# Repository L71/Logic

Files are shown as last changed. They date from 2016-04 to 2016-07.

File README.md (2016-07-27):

Logic signal processing Eurorack modules
========================================

* 4520 - 8bit binary counter/clock divider. Can trigger on both clock signal edges (determined by which input is used). 

* 234 - Sync clock divider, one pulse out for every 2,3 or 4 in. 

* Trigger - small module with 2x gate rising edge detectors, 2x inverters with button. Additional ORed output for the two edge detector outputs.

Panels and PCBs licensed cc-by-sa.

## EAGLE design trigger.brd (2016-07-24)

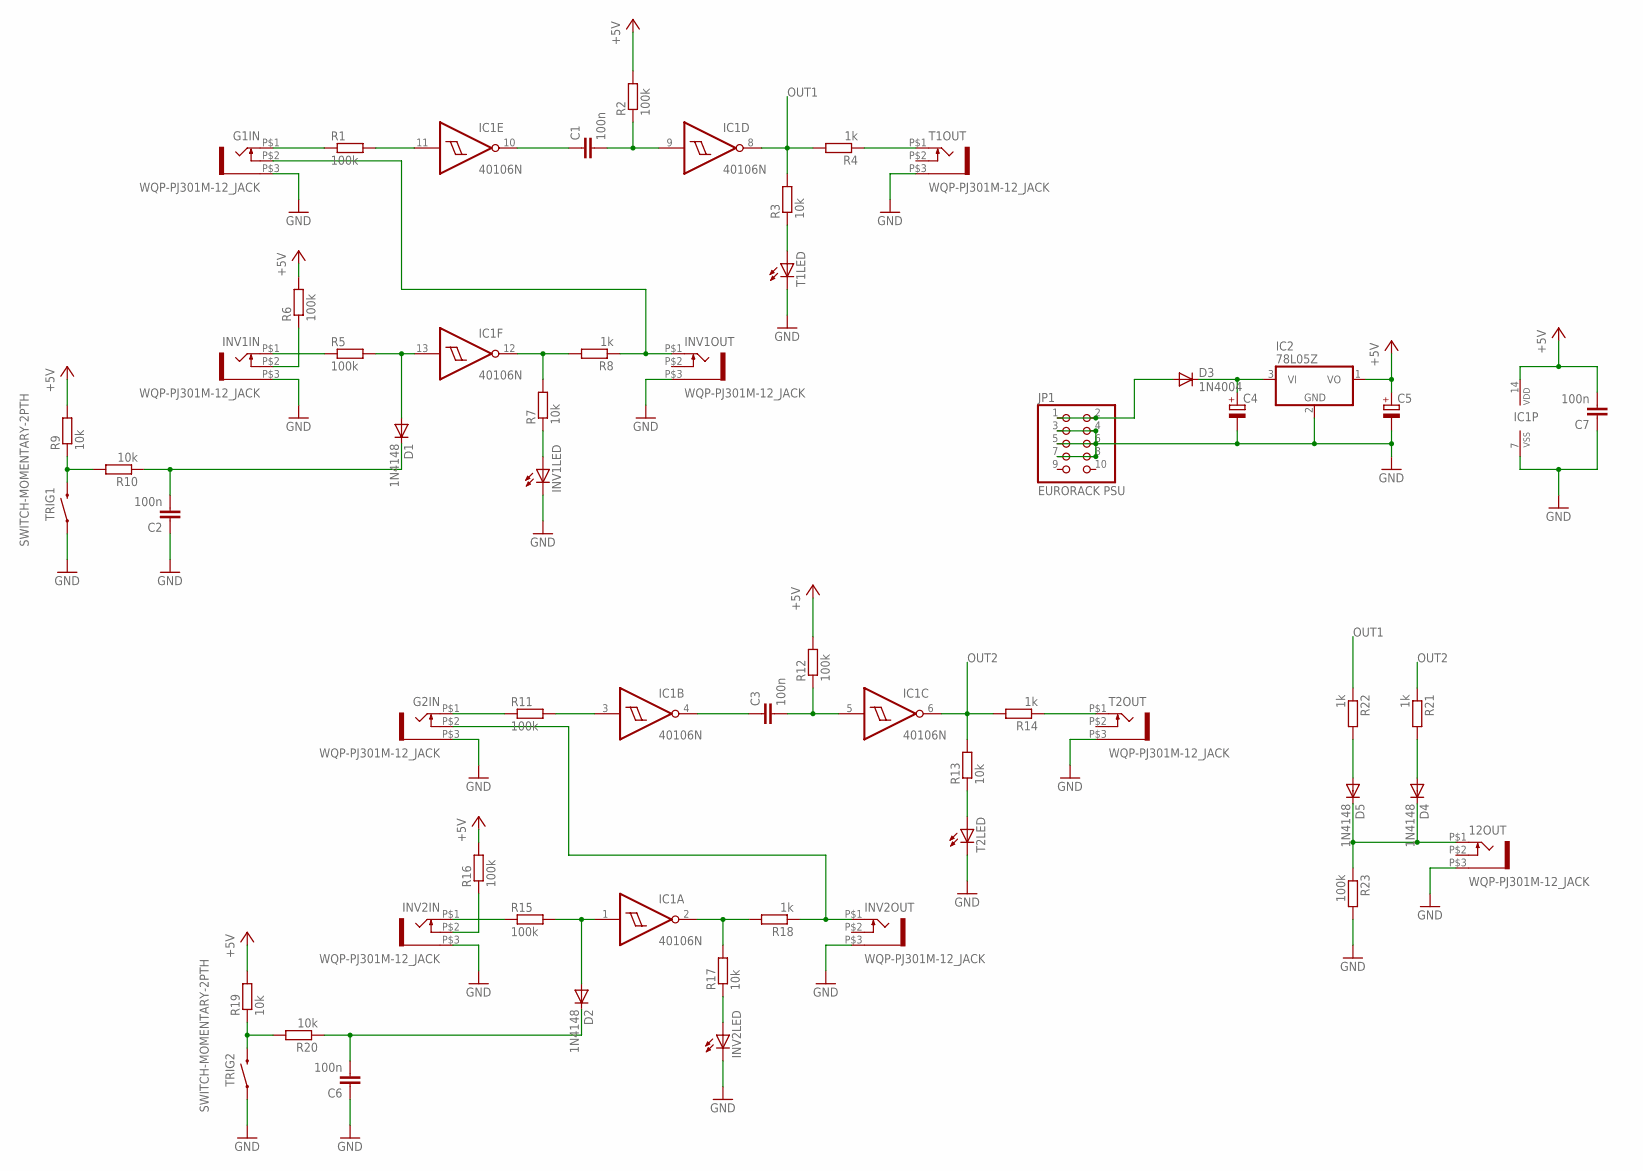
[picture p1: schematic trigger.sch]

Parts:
12OUT: WQP-PJ301M-12_JACK
C1, C2, C3, C6, C7: 100n; C025-025X050
C4, C5: CPOL-EUE2.5-5; E2,5-5
D1, D2, D4, D5: 1N4148; D-2.5
D3: 1N4004; D-2.5
G1IN, G2IN: WQP-PJ301M-12_JACK
IC1: 40106N; DIL14
IC2: 78L05Z; TO92
INV1IN, INV1OUT, INV2IN, INV2OUT: WQP-PJ301M-12_JACK
INV1LED, INV2LED: LED3MM
JP1: EURORACK PSU; 2X05
R1, R2, R5, R6, R11, R12, R15, R16, R23: 100k; 0204V
R3, R7, R9, R10, R13, R17, R19, R20: 10k; 0204V
R4, R8, R14, R18, R21, R22: 1k; 0204V
T1LED, T2LED: LED3MM
T1OUT, T2OUT: WQP-PJ301M-12_JACK
TRIG1, TRIG2: SWITCH-MOMENTARY-2PTH; TACTILE-PTH

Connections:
+5V: C5.+, C7.2, IC1.14 (VDD), IC2.1 (VO), R2.2, R6.2, R9.2, R12.2, R16.2, R19.2
+12V_IN: D3.A, JP1.1, JP1.2
GND: 12OUT.P$3 (1), C2.1, C4.-, C5.-, C6.1, C7.1, G1IN.P$3 (1), G2IN.P$3 (1), IC1.7 (VSS), IC2.2 (GND), INV1IN.P$3 (1), INV1LED.K (C), INV1OUT.P$3 (1), INV2IN.P$3 (1), INV2LED.K (C), INV2OUT.P$3 (1), JP1.3, JP1.4, JP1.5, JP1.6, JP1.7, JP1.8, R23.2, T1LED.K (C), T1OUT.P$3 (1), T2LED.K (C), T2OUT.P$3 (1), TRIG1.1, TRIG2.1
IN_1: G1IN.P$1 (2), R1.1
unnamed: 12OUT.P$1 (2), D4.C, D5.C, R23.1
unnamed: IC1.11 (I), R1.2
unnamed: C1.1, IC1.10 (O)
unnamed: C1.2, IC1.9 (I), R2.1
unnamed: D5.A, R22.2
unnamed: R3.1, T1LED.A
unnamed: R4.1, T1OUT.P$1 (2)
unnamed: IC1.12 (O), R7.2, R8.2
unnamed: INV1LED.A, R7.1
unnamed: G1IN.P$2 (3), INV1OUT.P$1 (2), R8.1
unnamed: INV1IN.P$1 (2), R5.1
unnamed: D1.A, IC1.13 (I), R5.2
unnamed: INV1IN.P$2 (3), R6.1
unnamed: C4.+, D3.C, IC2.3 (VI)
unnamed: R9.1, R10.2, TRIG1.3 (2)
unnamed: C2.2, D1.C, R10.1
unnamed: G2IN.P$1 (2), R11.1
unnamed: IC1.3 (I), R11.2
unnamed: C3.1, IC1.4 (O)
unnamed: C3.2, IC1.5 (I), R12.1
unnamed: D4.A, R21.2
unnamed: R13.1, T2LED.A
unnamed: R14.1, T2OUT.P$1 (2)
unnamed: IC1.2 (O), R17.2, R18.2
unnamed: INV2LED.A, R17.1
unnamed: G2IN.P$2 (3), INV2OUT.P$1 (2), R18.1
unnamed: INV2IN.P$1 (2), R15.1
unnamed: D2.A, IC1.1 (I), R15.2
unnamed: INV2IN.P$2 (3), R16.1
unnamed: R19.1, R20.2, TRIG2.3 (2)
unnamed: C6.2, D2.C, R20.1
OUT1: IC1.8 (O), R3.2, R4.2, R22.1
OUT2: IC1.6 (O), R13.2, R14.2, R21.1

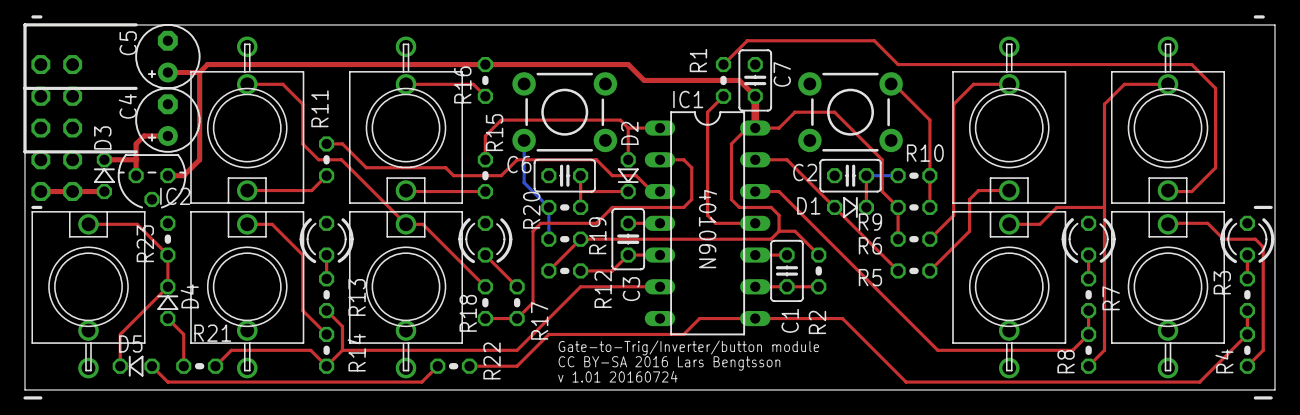
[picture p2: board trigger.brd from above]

Board: 2 copper layers, 100.0 x 29.2 mm, 53 parts (1 on the bottom side), 37 nets.

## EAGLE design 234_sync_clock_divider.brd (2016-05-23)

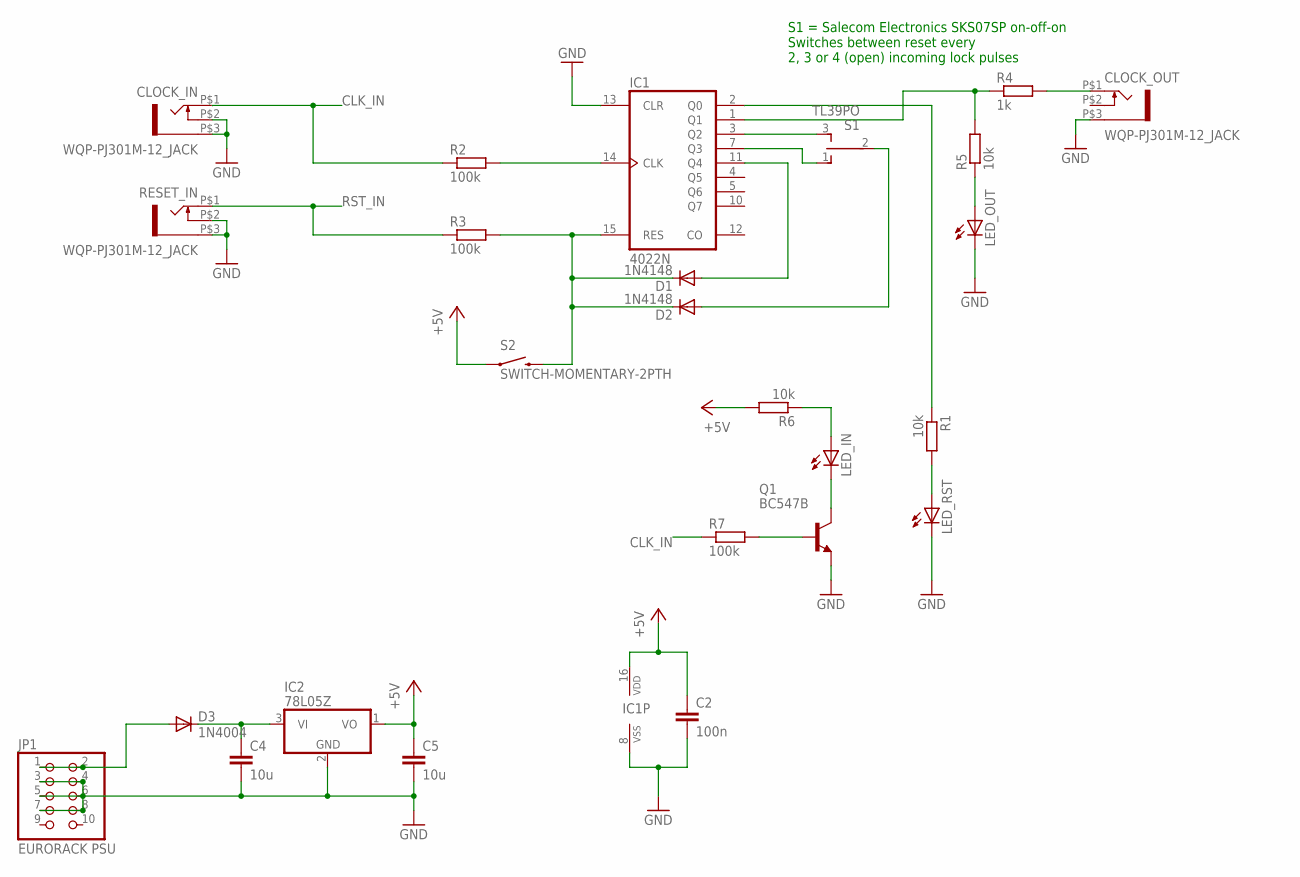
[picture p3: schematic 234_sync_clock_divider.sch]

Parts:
C2: 100n; C025-025X050
C4, C5: 10u; C1206K
CLOCK_IN: WQP-PJ301M-12_JACK
CLOCK_OUT: WQP-PJ301M-12_JACK
D1, D2: 1N4148; D-2.5
D3: 1N4004; D-2.5
IC1: 4022N; DIL16
IC2: 78L05Z; TO92
JP1: EURORACK PSU; 2X05
LED_IN: LED3MM
LED_OUT: LED3MM
LED_RST: LED3MM
Q1: BC547B; TO92
R1, R5, R6: 10k; 0204V
R2, R3, R7: 100k; 0204V
R4: 1k; 0204V
RESET_IN: WQP-PJ301M-12_JACK
S1: TL39PO; TL3XPO
S2: SWITCH-MOMENTARY-2PTH; TACTILE-PTH

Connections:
+5V: C2.1, C5.1, IC1.16 (VDD), IC2.1 (VO), R6.2, S2.1
+12V_IN: D3.A, JP1.1, JP1.2
CLK_IN: CLOCK_IN.P$1 (2), R2.1, R7.1
GND: C2.2, C4.2, C5.2, CLOCK_IN.P$2 (3), CLOCK_IN.P$3 (1), CLOCK_OUT.P$3 (1), IC1.8 (VSS), IC1.13 (CLR), IC2.2 (GND), JP1.3, JP1.4, JP1.5, JP1.6, JP1.7, JP1.8, LED_OUT.K (C), LED_RST.K (C), Q1.1 (E), RESET_IN.P$2 (3), RESET_IN.P$3 (1)
unnamed: LED_RST.A, R1.2
unnamed: IC1.14 (CLK), R2.2
unnamed: D1.C, D2.C, IC1.15 (RES), R3.2, S2.3 (2)
unnamed: IC1.2 (Q0), R1.1
unnamed: IC1.1 (Q1), R4.1, R5.2
unnamed: CLOCK_OUT.P$1 (2), R4.2
unnamed: LED_OUT.A, R5.1
unnamed: D1.A, IC1.11 (Q4)
unnamed: IC1.3 (Q2), S1.3 (S)
unnamed: IC1.7 (Q3), S1.1 (O)
unnamed: D2.A, S1.2
unnamed: C4.1, D3.C, IC2.3 (VI)
unnamed: LED_IN.A, R6.1
unnamed: LED_IN.K (C), Q1.3 (C)
unnamed: Q1.2 (B), R7.2
RST_IN: R3.1, RESET_IN.P$1 (2)

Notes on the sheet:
S1 = Salecom Electronics SKS07SP on-off-on Switches between reset every 2, 3 or 4 (open) incoming lock pulses

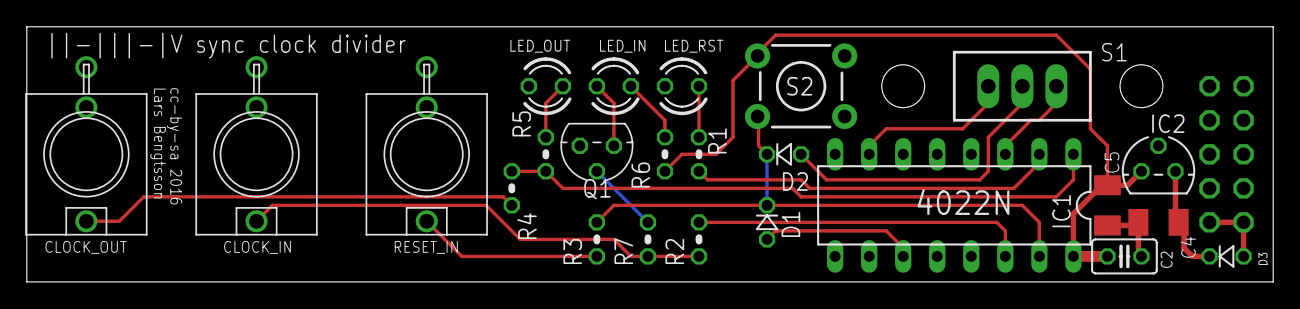
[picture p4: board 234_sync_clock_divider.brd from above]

Board: 2 copper layers, 93.0 x 19.0 mm, 25 parts (1 on the bottom side), 20 nets.

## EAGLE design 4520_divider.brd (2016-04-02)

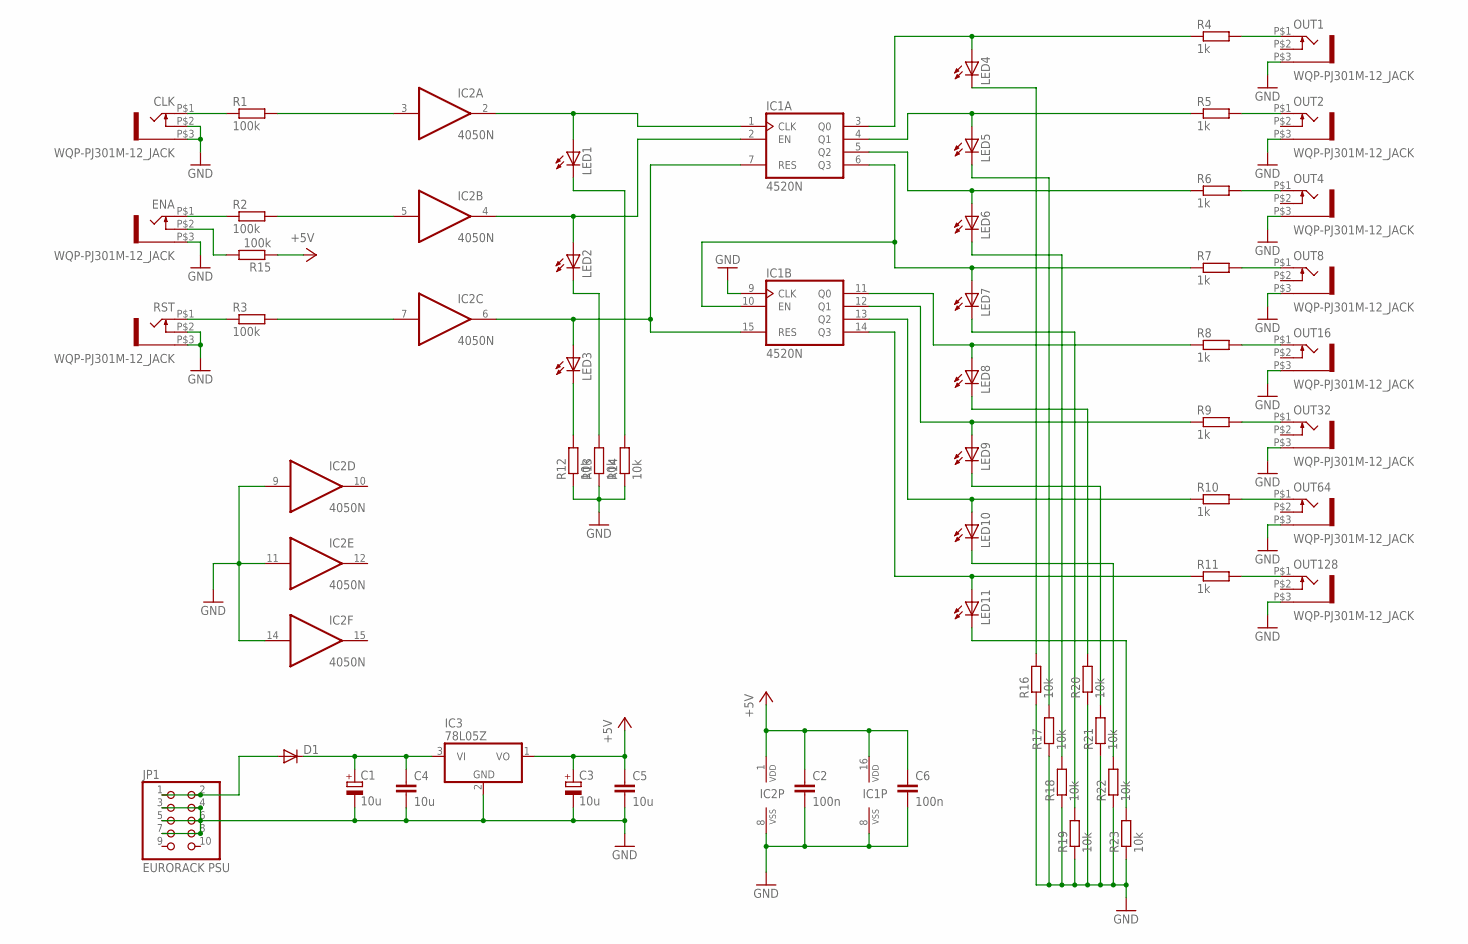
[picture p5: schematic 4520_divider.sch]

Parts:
C1, C3: 10u; E2,5-5
C2, C6: 100n; C025-025X050
C4, C5: 10u; C1206K
CLK: WQP-PJ301M-12_JACK
D1: DIODE-D-2.5; D-2.5
ENA: WQP-PJ301M-12_JACK
IC1: 4520N; DIL16
IC2: 4050N; DIL16
IC3: 78L05Z; TO92
JP1: EURORACK PSU; 2X05
LED1, LED2, LED3, LED4, LED5, LED6, LED7, LED8, LED9, LED10, LED11: LED3MM
OUT1, OUT2, OUT4, OUT8, OUT16, OUT32, OUT64, OUT128: WQP-PJ301M-12_JACK
R1, R2, R3, R15: 100k; 0204V
R4, R5, R6, R7, R8, R9, R10, R11: 1k; R1206
R12, R13, R14, R16, R17, R18, R19, R20, R21, R22, R23: 10k; R1206
RST: WQP-PJ301M-12_JACK

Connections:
+5V: C2.1, C3.+, C5.1, C6.1, IC1.16 (VDD), IC2.1 (VDD), IC3.1 (VO), R15.1
+12V_IN: D1.A, JP1.1, JP1.2
GND: C1.-, C2.2, C3.-, C4.2, C5.2, C6.2, CLK.P$2 (3), CLK.P$3 (1), ENA.P$3 (1), IC1.8 (VSS), IC1.9 (CLK), IC2.8 (VSS), IC2.9 (I), IC2.11 (I), IC2.14 (I), IC3.2 (GND), JP1.3, JP1.4, JP1.5, JP1.6, JP1.7, JP1.8, OUT1.P$3 (1), OUT2.P$3 (1), OUT4.P$3 (1), OUT8.P$3 (1), OUT16.P$3 (1), OUT32.P$3 (1), OUT64.P$3 (1), OUT128.P$3 (1), R12.1, R13.1, R14.1, R16.1, R17.1, R18.1, R19.1, R20.1, R21.1, R22.1, R23.1, RST.P$2 (3), RST.P$3 (1)
unnamed: OUT1.P$1 (2), R4.2
unnamed: IC1.4 (Q1), LED5.A, R5.1
unnamed: IC1.3 (Q0), LED4.A, R4.1
unnamed: LED4.K (C), R16.2
unnamed: OUT2.P$1 (2), R5.2
unnamed: OUT4.P$1 (2), R6.2
unnamed: C1.+, C4.1, D1.C, IC3.3 (VI)
unnamed: IC1.5 (Q2), LED6.A, R6.1
unnamed: LED5.K (C), R17.2
unnamed: LED6.K (C), R18.2
unnamed: LED7.K (C), R19.2
unnamed: LED8.K (C), R20.2
unnamed: LED9.K (C), R21.2
unnamed: LED10.K (C), R22.2
unnamed: LED11.K (C), R23.2
unnamed: OUT8.P$1 (2), R7.2
unnamed: OUT16.P$1 (2), R8.2
unnamed: OUT32.P$1 (2), R9.2
unnamed: OUT64.P$1 (2), R10.2
unnamed: OUT128.P$1 (2), R11.2
unnamed: IC1.6 (Q3), IC1.10 (EN), LED7.A, R7.1
unnamed: IC1.11 (Q0), LED8.A, R8.1
unnamed: IC1.12 (Q1), LED9.A, R9.1
unnamed: IC1.13 (Q2), LED10.A, R10.1
unnamed: IC1.14 (Q3), LED11.A, R11.1
unnamed: IC2.3 (I), R1.2
unnamed: IC2.5 (I), R2.2
unnamed: IC1.1 (CLK), IC2.2 (O), LED1.A
unnamed: IC1.2 (EN), IC2.4 (O), LED2.A
unnamed: IC1.7 (RES), IC1.15 (RES), IC2.6 (O), LED3.A
unnamed: LED3.K (C), R12.2
unnamed: LED2.K (C), R13.2
unnamed: LED1.K (C), R14.2
unnamed: IC2.7 (I), R3.2
unnamed: CLK.P$1 (2), R1.1
unnamed: ENA.P$1 (2), R2.1
unnamed: R3.1, RST.P$1 (2)
unnamed: ENA.P$2 (3), R15.2

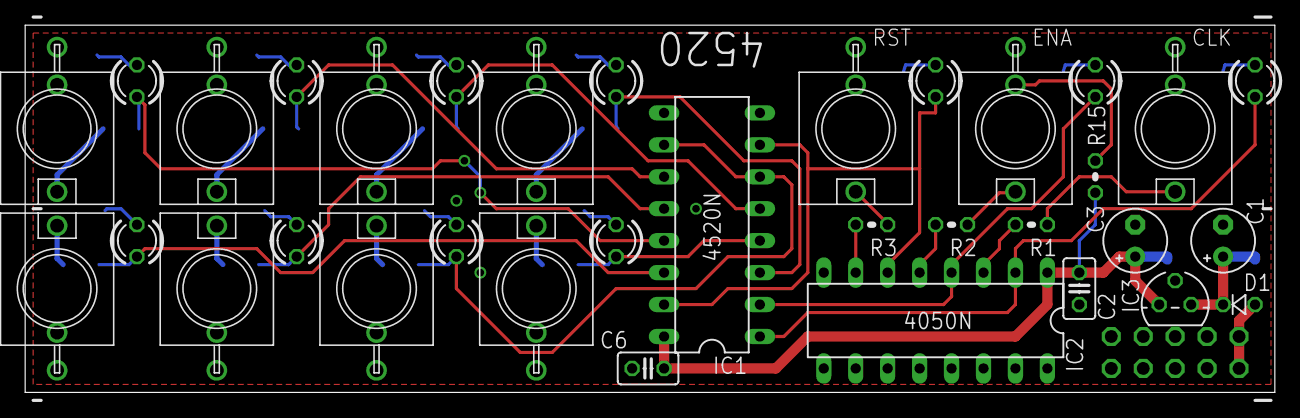
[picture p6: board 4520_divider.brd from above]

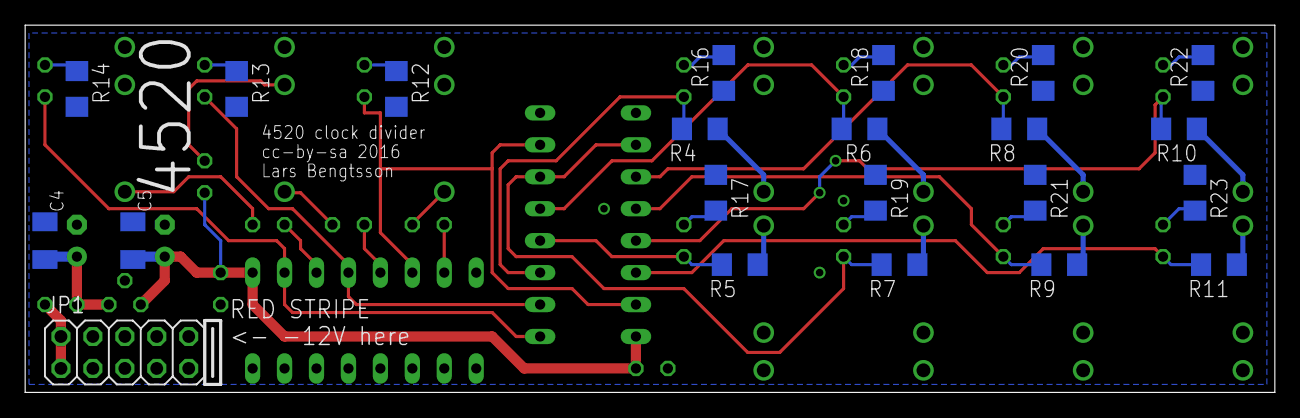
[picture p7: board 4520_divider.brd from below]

Board: 2 copper layers, 99.4 x 29.2 mm, 56 parts (22 on the bottom side), 41 nets.

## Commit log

2016-04-01 Initial commit of works in progress.
    [4520_divider.brd, 4520_divider.sch]
2016-04-02 Moved a few resistors for clarity.
    [4520_divider.sch]
2016-04-02 Moved labels, added top layer ground plane, added alternative 1206 caps in PSU curcuit for use when low-profile electrolytic caps are hard to find.
    [4520_divider.brd]
2016-04-02 Trimmed borders a bit.
    [4520_divider.brd]
2016-04-06 Initial add of 234 sync clock divider PCB + panel.
    [234_sync_clock_divider.brd, 234_sync_clock_divider.sch]
2016-04-11 Push button hole diameter increased to 3.5mm.
2016-05-23 Moved power connector - it was a bit too close to board edge. Added notice about CC license.
    [234_sync_clock_divider.brd]
2016-07-18 Initial add. This is a module with two trigger buttons/inverters/trigger edge detectors.
    [trigger.brd, trigger.sch]
2016-07-24 Minor routing improvement near common output. Added version/date stamp.
    [trigger.brd]

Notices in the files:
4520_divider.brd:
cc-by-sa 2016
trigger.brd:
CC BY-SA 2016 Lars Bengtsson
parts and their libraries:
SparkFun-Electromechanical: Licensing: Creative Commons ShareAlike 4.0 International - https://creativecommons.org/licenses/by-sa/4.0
